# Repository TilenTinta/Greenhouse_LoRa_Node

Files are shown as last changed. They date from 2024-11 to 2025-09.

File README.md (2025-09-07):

# Greenhouse LoRa Node

**Greenhouse LoRa Node** is an open-source monitoring system designed for use in greenhouses, orchards or other agricultural environments. This project includes all the necessary components to build the system, including:

- A custom PCB for the node (supports LoRa or SIM card communication),
- Firmware for the PCB,
- PCB casing,
- Server terminal application,
- GUI template using Grafana.

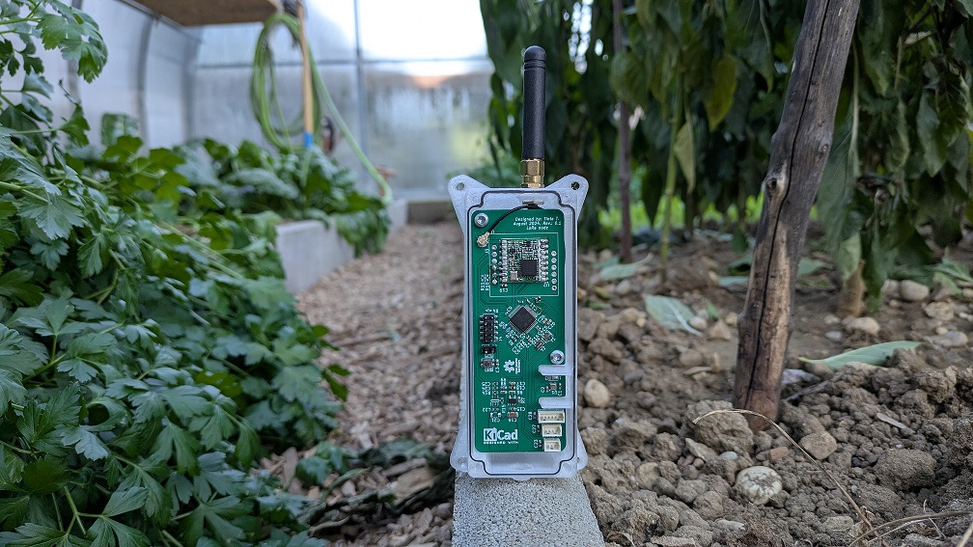
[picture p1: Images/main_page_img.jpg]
Greenhouse LoRa Node


---

## PCB

The PCB is a two-layer board that integrates essential hardware components. It is versatile and supports different communication modules. Users can choose between a LoRa module or a SIM card module (both cannot be used simultaneously). 

### Features
- LDO voltage regulator - 3.3V for mcu and sensors.
- Direct battery power if STM32L151 is used,
- Step-up converter - 4V for SIM module only,
- Battery voltage monitoring,
- Battery cell holder for 18650 cells,
- Three connectors:
  - Earth humidity probe
  - AUX1 (I2C interface)
  - AUX2 (SPI interface),
- Support for LoRa module (RFM95W / SX1276) or SIM module (SIM800L),
- u.FL antenna connector,
- BME280 sensor (measures air temperature, humidity, and pressure),
- MCU: STM32F103C8T6 or STM32L151C8T6,
- 10-pin JTAG programming connector.

---

## Firmware

The firmware is written entirely in C using STM CubeIDE. It is designed to be easily updated or modified. The MCU supports multiple sleep modes for power optimization, which can be configured directly in the code.

The project does not include the `keys.h` file, as it contains user-specific information. The structure of the `keys.h` file is as follows:

```c
#ifndef KEYS_H_
#define KEYS_H_

#define DEVICE_ID            1       // ID number of the node

#define DEVICE_ADDRESS       {0x01, 0x23, 0x45, 0x56}
#define APPSKEY              {0x01, 0x23, 0x45, 0x67, 0x89, 0x10, 0x11, 0x12, 0x13, 0x14, 0x15, 0x16, 0x17, 0x18, 0x19, 0x20}
#define NWKSKEY              {0x01, 0x23, 0x45, 0x67, 0x89, 0x10, 0x11, 0x12, 0x13, 0x14, 0x15, 0x16, 0x17, 0x18, 0x19, 0x20}

#endif
```

The library for the RFM95W LoRa module is based on the repository linked below, with slight modifications made for this project: [https://github.com/henriheimann/stm32-hal-rfm95](https://github.com/henriheimann/stm32-hal-rfm95)

> [!CAUTION]
> When using the **RFM95W LoRa module** and the graphical peripheral editor in **CubeIDE**, additional code modifications are required. After saving changes in the IDE, the auto-generated code will be overwritten, re-enabling all IRQs by default. 
> The **RFM95W module** generates a 1 MHz digital signal on one of its IRQ pins at boot. If interrupts are not properly initialized, this can trigger errors in the MCU. To prevent this issue, **all interrupts must be disabled until the module is fully initialized**.

This project includes two firmware versions for two different microcontrollers. The firmware in the `Firmware_F103` folder was written for the STM32F103xx microcontroller and represents the initial version of the firmware. Due to issues with power consumption, the microcontroller was replaced with an STM32L151xx. The firmware in the `Firmware_L151` folder is the latest version, incorporating all modifications made to the PCB.

### Current consumption:
The current firmware is optimized for the LoRa module and uses Standby sleep mode. In this configuration, the PCB draws ~60 µA while asleep. This isn’t ideal yet, but it’s sufficient for initial tests. Bench measurements suggest the remaining overhead lies between the MCU and the RFM95W.
At 60 µA, a 3500 mAh 18650 cell yields a theoretical battery life of ~6 years, not accounting for self-discharge, temperature...

---

## Case

The PCB case is 3D printed using PETG filament on a standard FDM 3D printer. When deploying the node outdoors, ensure the filament can withstand UV exposure. Materials like ASA or ABS might be more suitable for such environments.

### Design Features:
- The case has a dedicated section with perforations to allow airflow near the sensor, enabling accurate air parameter measurements while protecting the rest of the PCB from external conditions.
- A groove runs along the perimeter of the lower part of the case, designed to fit a 3D-printed seal made from flexible materials like TPU or TPE. This ensures a better seal to protect the internal components.

### Notes:
- The design is optimized for easy replication using commonly available 3D printing materials and techniques.
- Consider using higher-temperature and UV-resistant materials for long-term outdoor use.

---

## Server Application

The server application is entirely written in Python and is terminal-based. Every operation performed by the application is logged into a log file for future inspection in case of issues. 

### Features
- Connects to your LoRaWAN devices on TTN via MQTT.
- Configurable `ttn_config.json` for easy integration.
- Configurable `InfluxDB_config.json` for easy integration.
- Supports multiple devices under a single application.

### Configuration Files

Upon boot, the application requires two JSON files to load all the configurations for the database and MQTT connection to the TTN broker:

1. **`InfluxDB_config.json`**  
   Configuration file for connecting to the InfluxDB database:
   ```json
   {
       "_comment": "JSON config file for database connection",
       "url": "http://localhost:8086",
       "org": "tinta",
       "token": "XXXXXXXXXXXXXXXXXXXXXXXXXXXXXXXXXXXXXXXXXX",
       "bucket": "bucket_name",
       "timezone": "Europe/Ljubljana"
   }
    ```

2. **`ttn_config.json`** 
    ```json
    {
        "_comment": "JSON config file for mqttTTN connection",
        "app_id": "lora-home-node",
        "username": "lora-home-node@ttn",
        "access_key": "XXXXXXXXXXXXXXXXXXXXXXXXXXX.XXXXXXXXXXXXXXXXXXXXXXXXX",
        "mqtt_broker": "eu1.cloud.thethings.network",
        "mqtt_port": 1883,
        "topic": "v3/lora-home-node@ttn/devices/+/up" 
    }
    ```

### Prerequirements

Before running the application, ensure you have the required dependencies installed. The following packages are necessary:

``` bash
pip install json paho-mqtt psycopg2 influxdb-client pytz logging socket base64
```

---

## Database

This project utilizes **InfluxDB** as its primary database solution. InfluxDB was selected due to its high efficiency in handling time-series data and its seamless integration with **Grafana**, which simplifies data visualization and analysis. By leveraging InfluxDB's ability to store data in a **time-series format**, this project ensures scalability for managing and analyzing temporal data.

### Notes:
- Ensure that InfluxDB is properly configured to handle the expected volume of data from the monitoring nodes.

---

## Grafana

This repository contains pre-configured Grafana UI files designed to read and present data from sensors in an intuitive and visually appealing way. These files provide a basic setup to help you quickly get started with monitoring and analyzing your sensor data using Grafana's powerful dashboard capabilities.

### Requirements:
- **Grafana** and **InfluxDB** should be installed on either a Raspberry Pi or a home server (depending on your setup).
- Ensure the terminal application is run on the same machine where the database and Grafana are installed.

---

## Docker Setup

This repository includes Docker support for easier and faster deployment on the server-side. The Docker setup contains:
- **InfluxDB** (Database)
- **Grafana** (Visualization Tool)
- **Python Server Application** (`server_app`)

> [!CAUTION]
Before running the Docker setup, the `docker-compose.yml` file must be modified to suit your specific preferences, such as:
- Network configurations,
- Volume mappings,
- Environment variables for InfluxDB, Grafana, and the Python application,
- Ports for external access,
- etc.

### Building the Container

To build the Docker containers, first navigate to the `Docker` folder in your terminal:

``` bash
cd /path/to/Docker
```
then run:
``` bash
docker-compose build
```
Once the container is build start it and set it up as you want.
``` bash
docker-compose up -d
```

### Acces containers
After running the containers, you can access:
- Grafana: http://localhost:3000 (default credentials: admin / admin123)
- InfluxDB: http://localhost:8086 (default credentials: admin / admin123)

Make sure your Grafana instance is properly configured to read from InfluxDB.

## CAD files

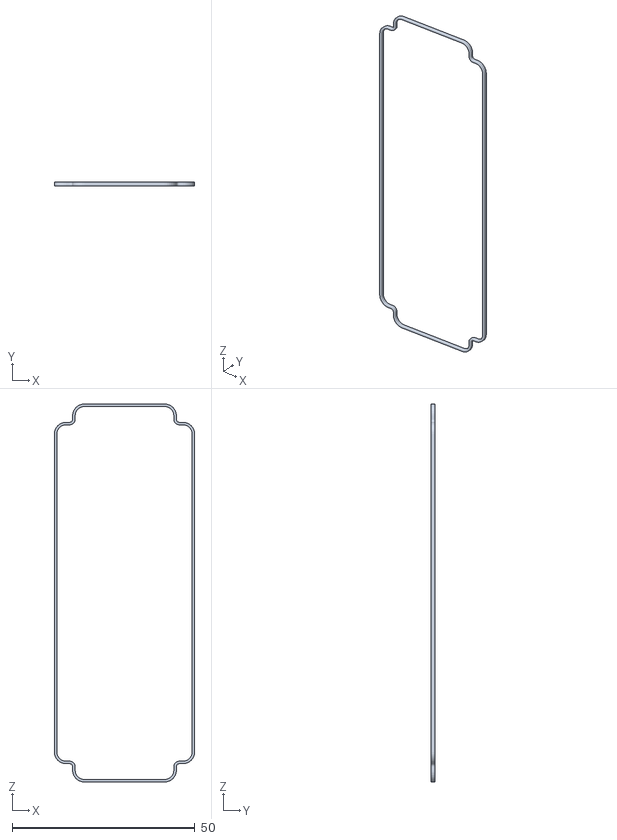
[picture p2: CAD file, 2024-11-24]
STL/Sealing v3.stl
38.4 x 1.10 x 103.4

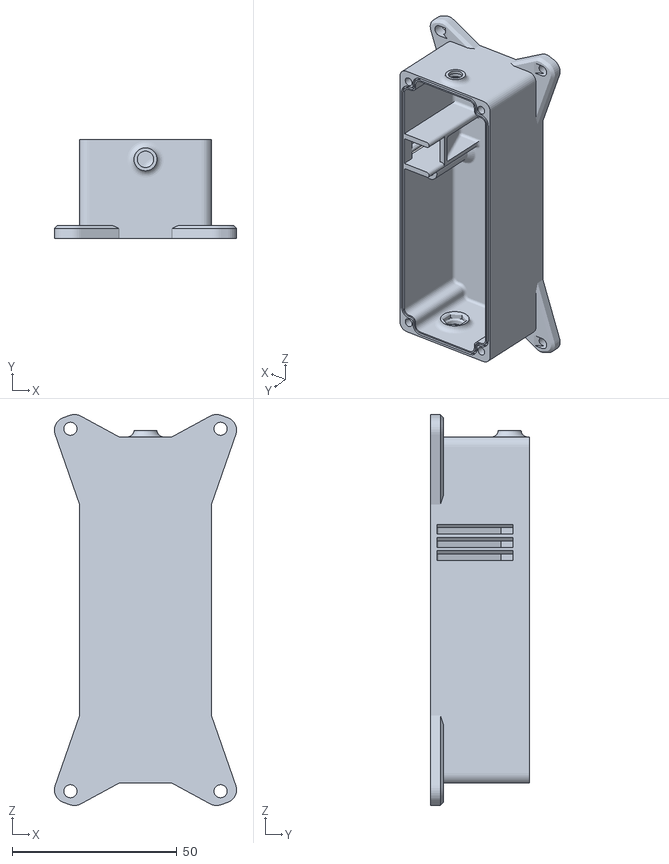
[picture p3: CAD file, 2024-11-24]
STL/PCB_case v31.stl
55.3 x 30.0 x 118.6

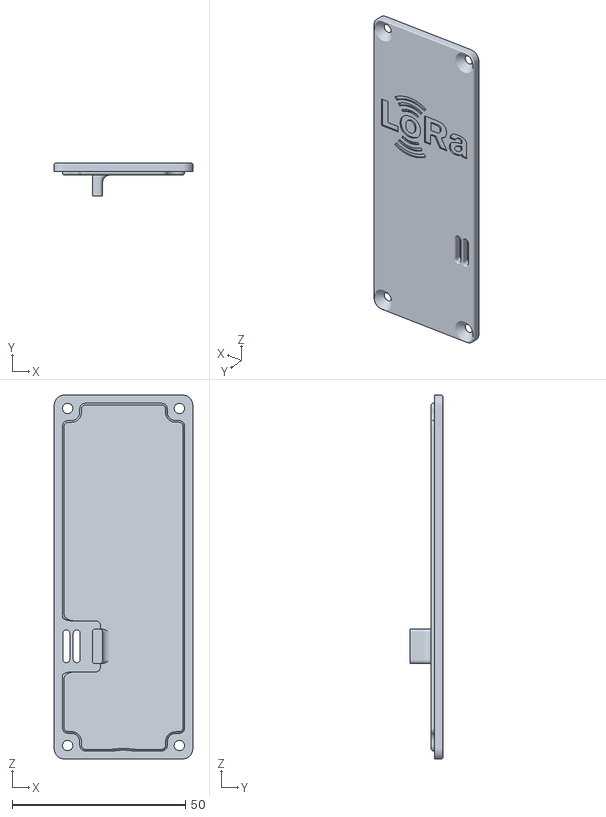
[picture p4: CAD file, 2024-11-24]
STL/PCB_lid v17.stl
40.0 x 9.50 x 105.0

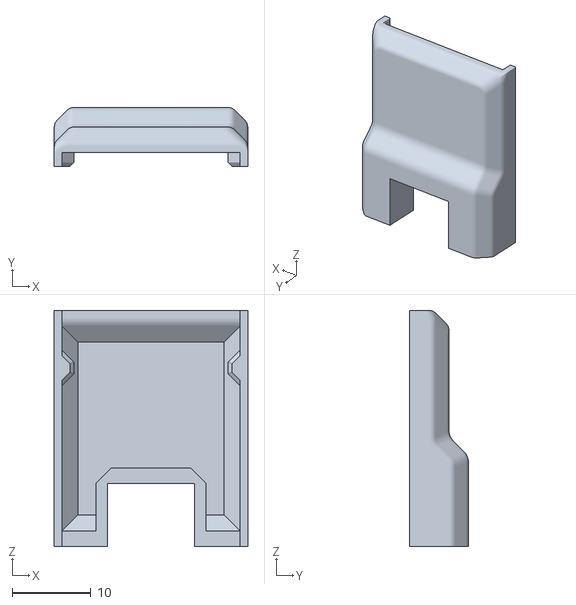
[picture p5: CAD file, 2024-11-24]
STL/Ground_sensor_cover v9.stl
24.6 x 7.50 x 30.0

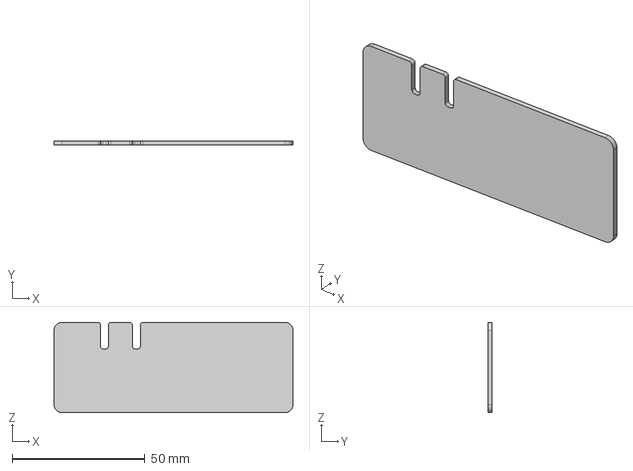
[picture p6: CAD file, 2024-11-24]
STL/PCB_base v15.step
90.0 x 1.60 x 34.0 mm

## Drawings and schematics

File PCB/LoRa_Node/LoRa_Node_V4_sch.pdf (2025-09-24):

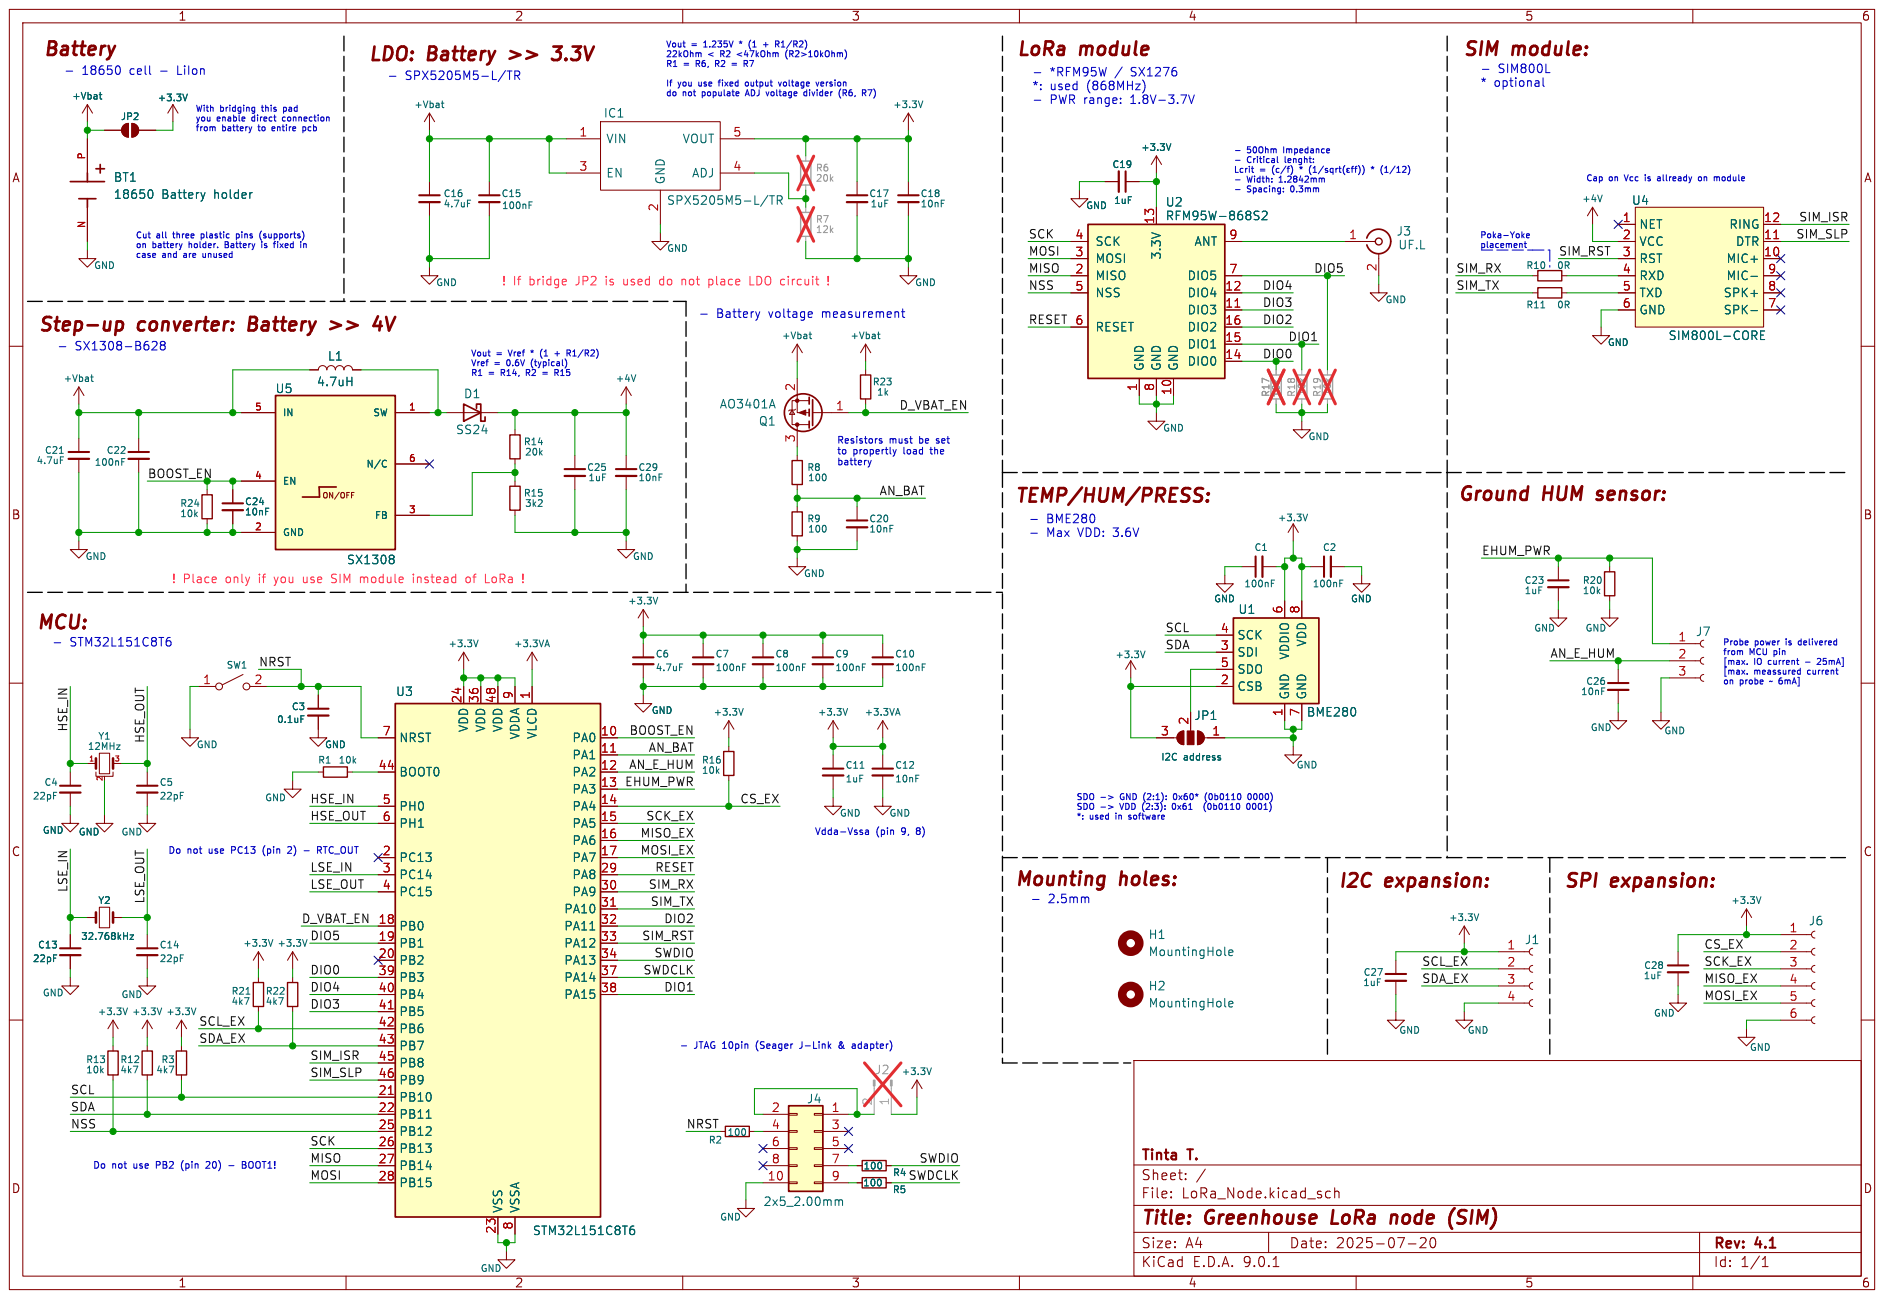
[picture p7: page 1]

RESET NSS LoRa module
+3.3V GND

you enable direct connection

case and are unused

- Max VDD: 3.6V Mounting holes:

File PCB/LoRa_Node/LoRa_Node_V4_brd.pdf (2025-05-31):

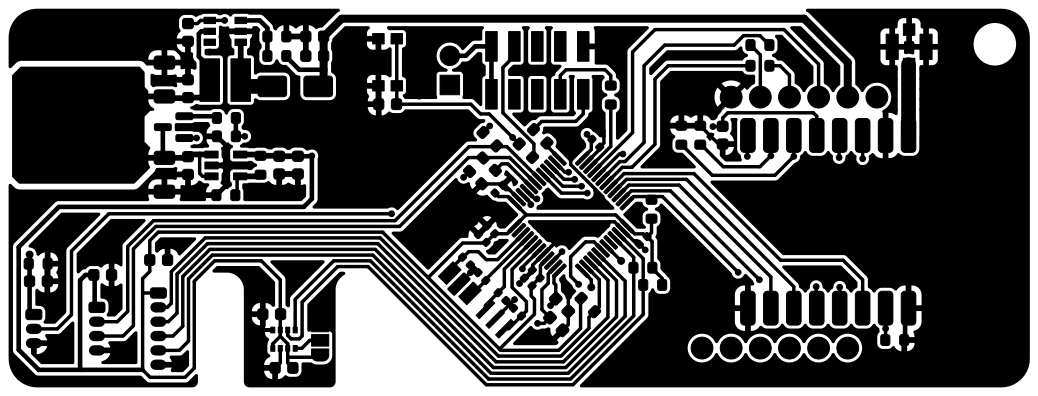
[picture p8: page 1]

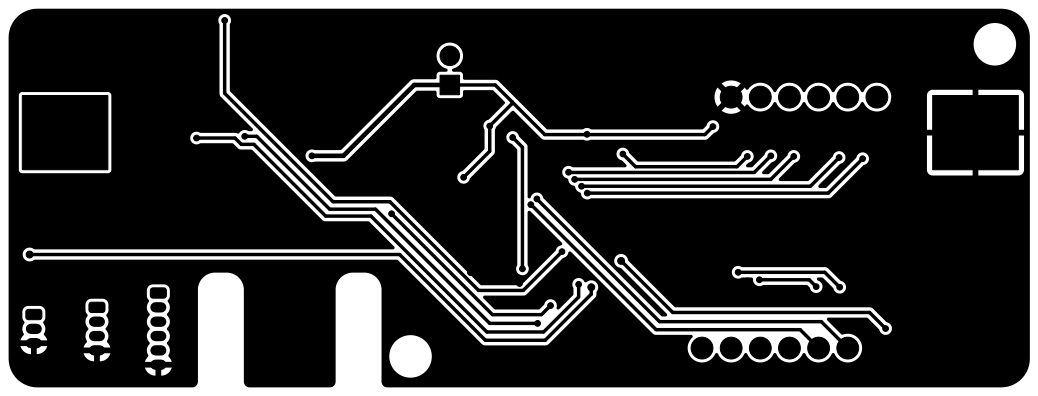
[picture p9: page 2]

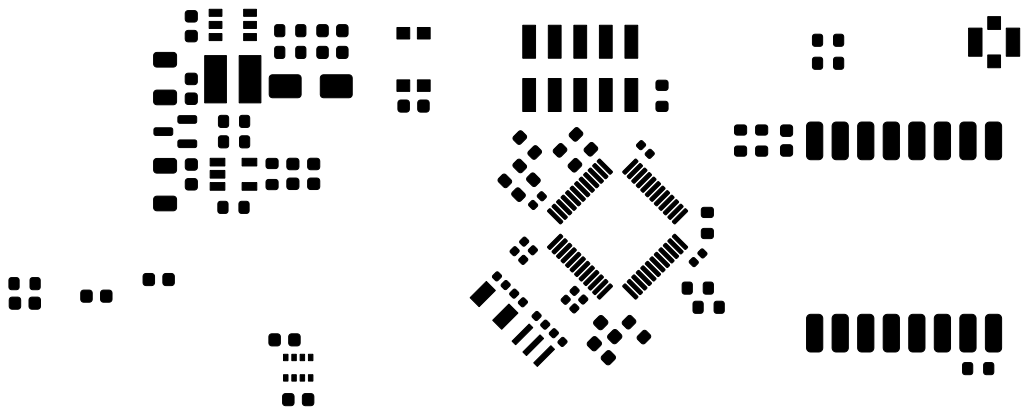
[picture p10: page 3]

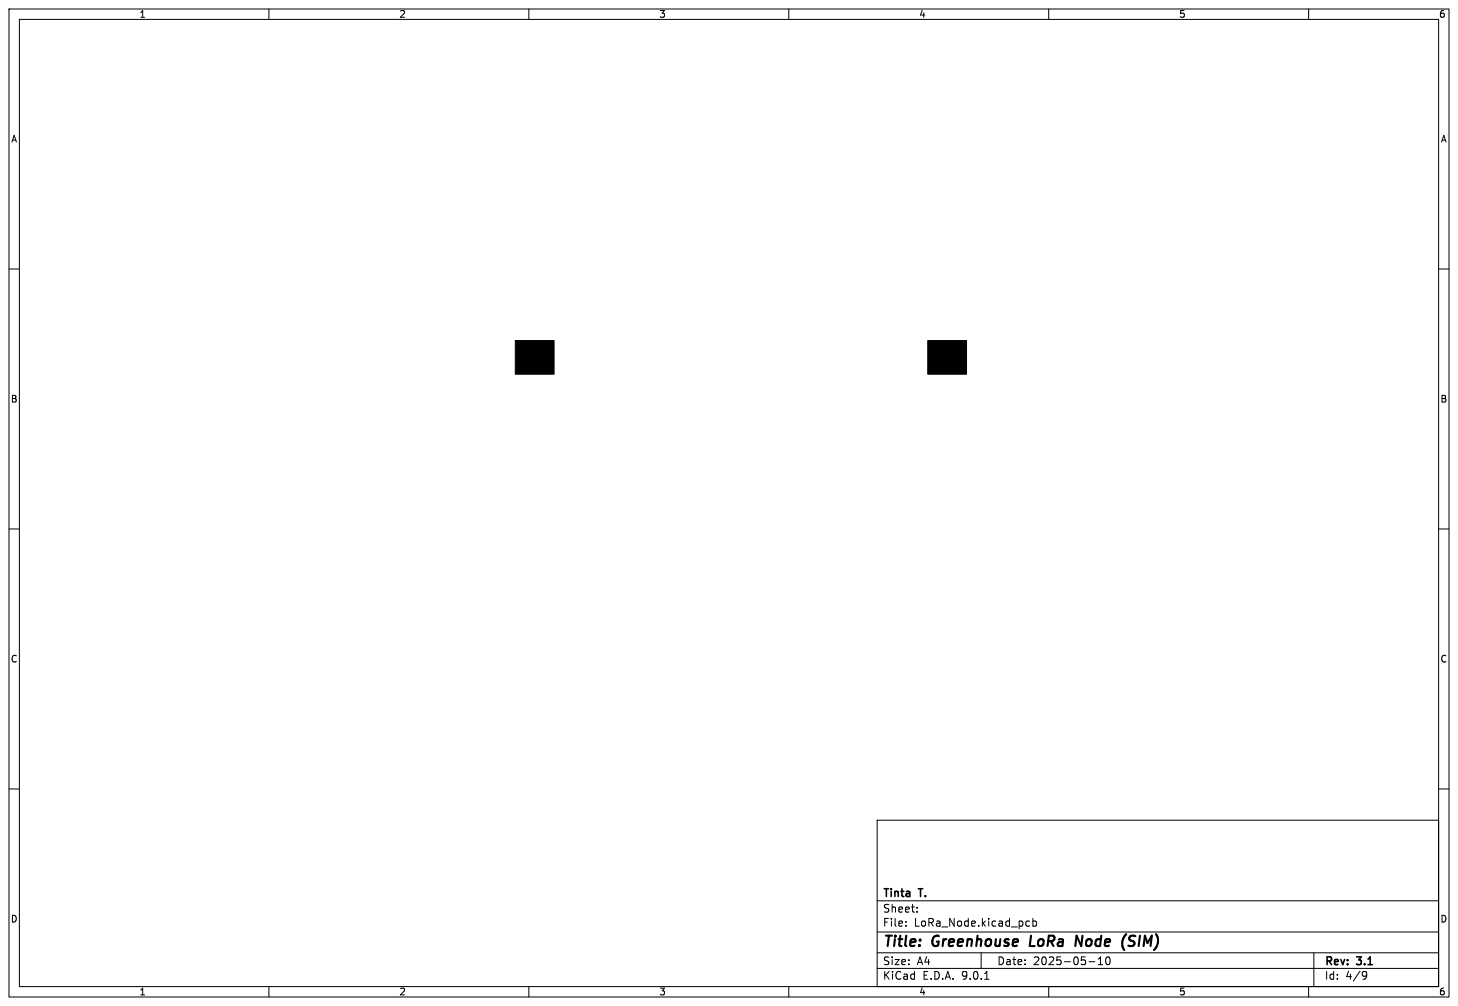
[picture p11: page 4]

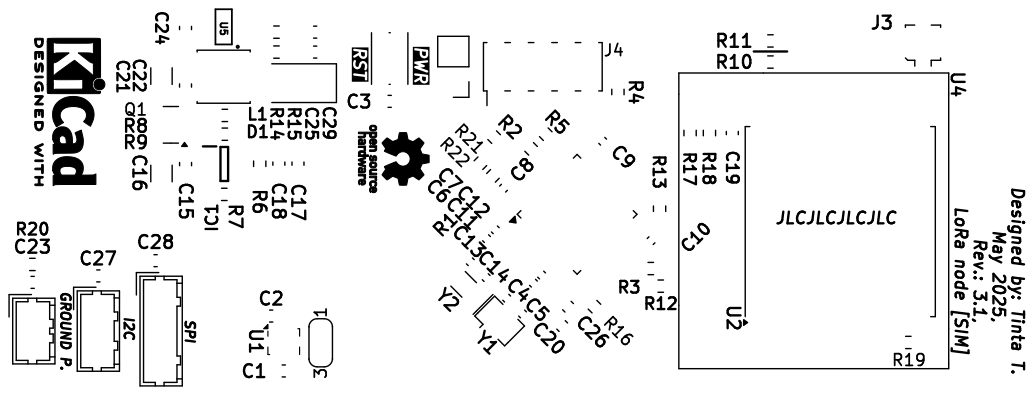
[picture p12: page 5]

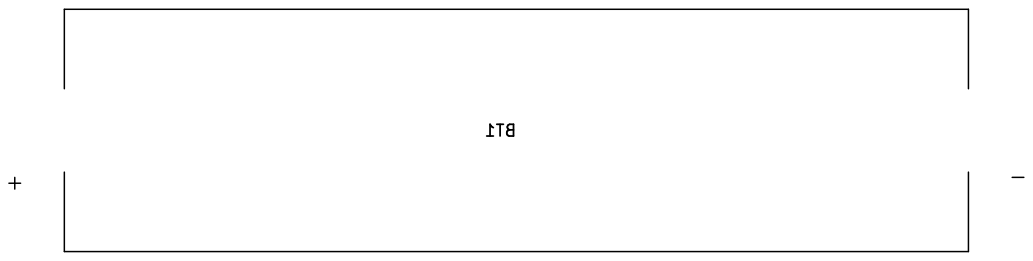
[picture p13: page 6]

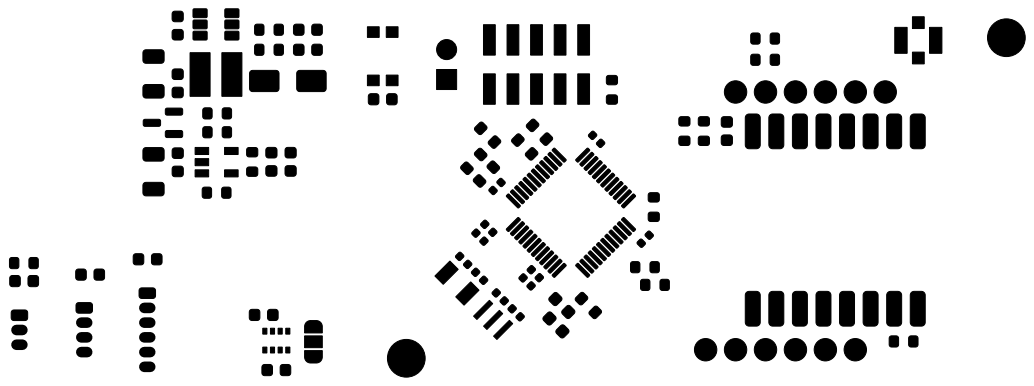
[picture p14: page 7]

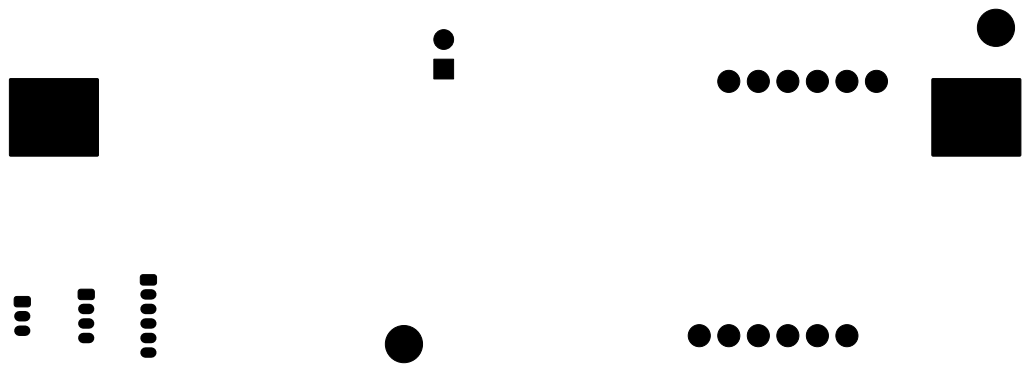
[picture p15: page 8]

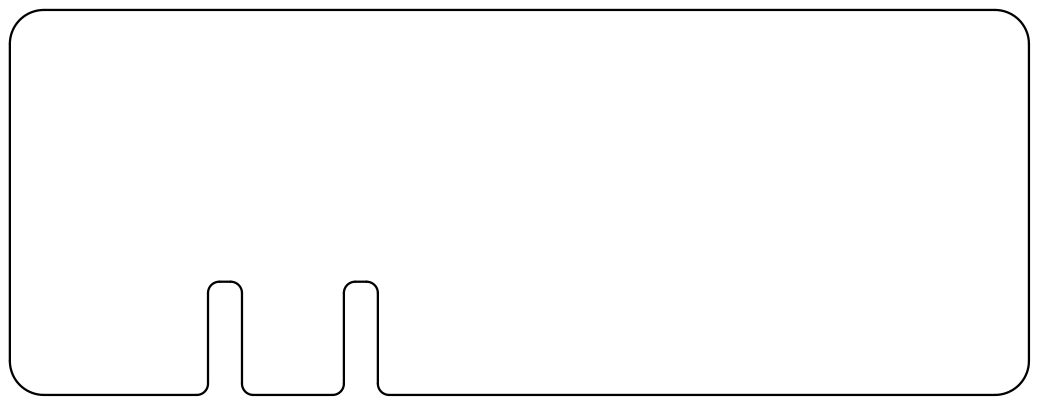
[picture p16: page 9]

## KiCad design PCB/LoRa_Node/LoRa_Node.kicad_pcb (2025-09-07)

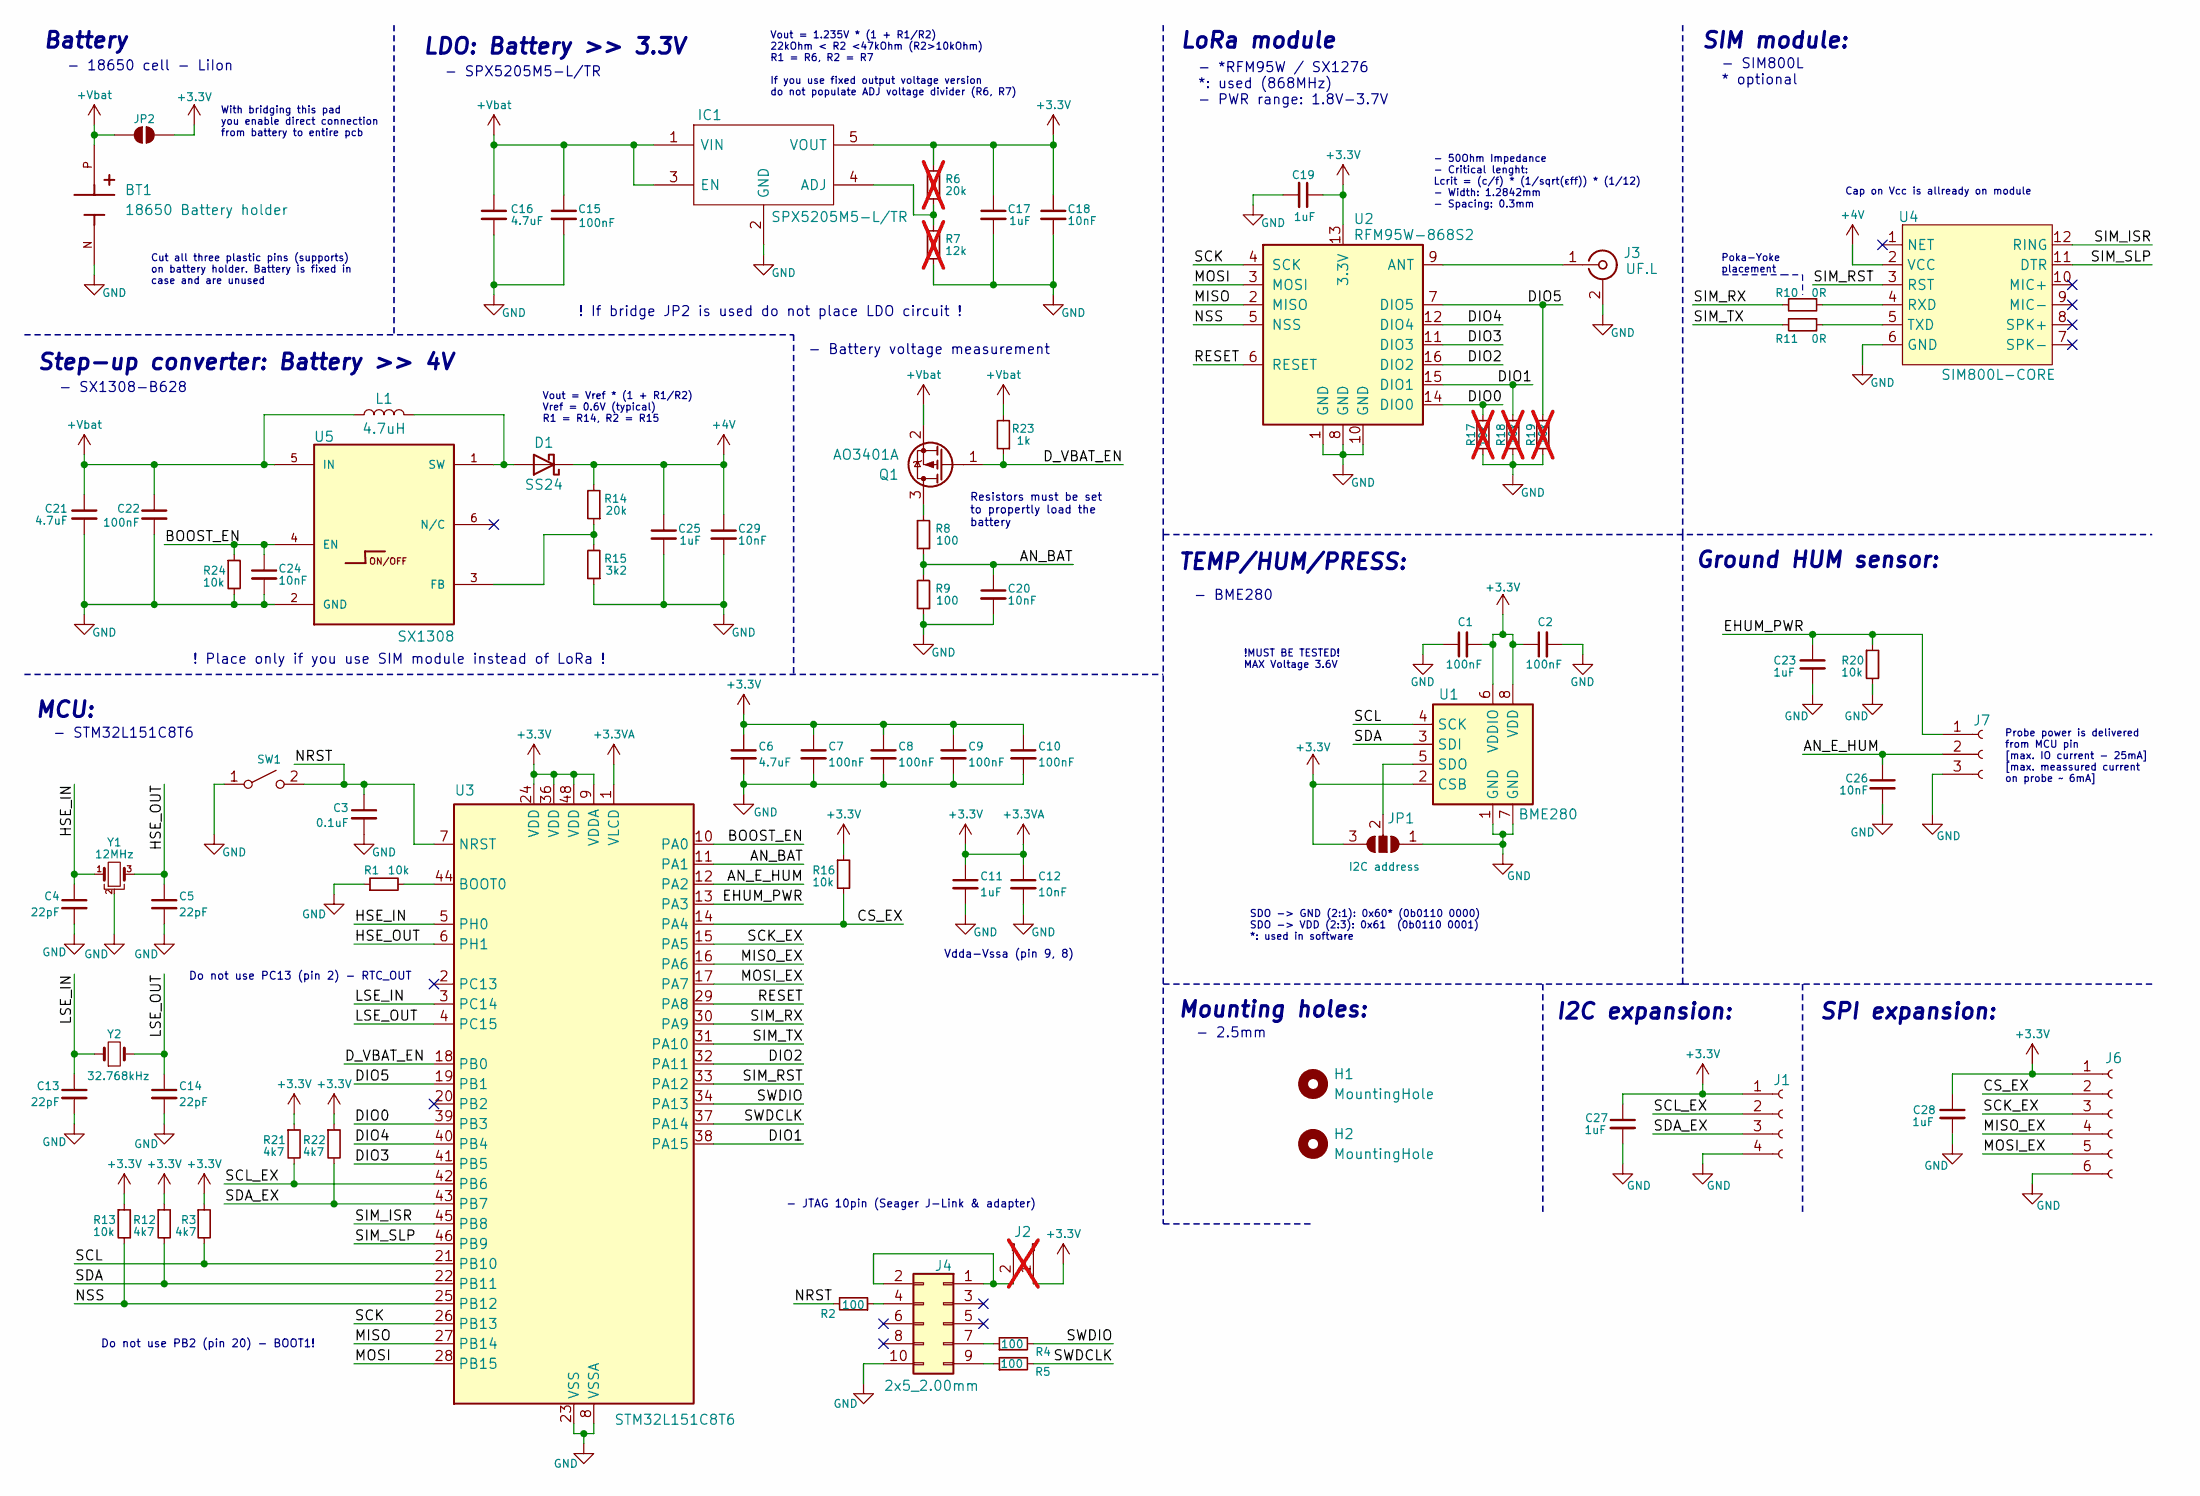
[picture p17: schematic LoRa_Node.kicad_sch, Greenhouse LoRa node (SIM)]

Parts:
BT1: 18650 Battery holder; PARTREV E
C1, C2, C15, C22: 100nF; C_0603_1608Metric
C3: 0.1uF; C_0603_1608Metric
C4, C5, C13, C14: 22pF; C_0402_1005Metric
C6: 4.7uF; C_0402_1005Metric
C7, C8, C9, C10: 100nF; C_0402_1005Metric
C11: 1uF; C_0402_1005Metric
C12: 10nF; C_0402_1005Metric
C16, C21: 4.7uF; C_1206_3216Metric
C17, C19, C23, C25, C27, C28: 1uF; C_0603_1608Metric
C18, C20, C24, C26, C29: 10nF; C_0603_1608Metric
D1: SS24; D_SMA
H1, H2: MountingHole; MountingHole_3.2mm_M3
IC1: SPX5205M5-L/TR; SOT95P280X145-5N; Manufacturer_Part_Number SPX5205M5-L-3-3/TR; Mouser Part Number 701-SPX5205M5-L-33TR
J1: Conn_01x04_Socket; Hirose_DF13-04P-1.25DSA_1x04_P1.25mm_Vertical
J2: Conn_01x02_Pin; PinHeader_1x02_P2.54mm_Vertical; not fitted
J3: UF.L; U.FL_Molex_MCRF_73412-0110_Vertical
J4: 2x5_2.00mm; PinHeader_2x05_P2.00mm_Vertical_SMD
J6: Conn_01x06_Socket; Hirose_DF13-06P-1.25DSA_1x06_P1.25mm_Vertical
J7: Conn_01x03_Socket; Hirose_DF13-03P-1.25DSA_1x03_P1.25mm_Vertical
JP1: I2C address; SolderJumper-3_P1.3mm_Open_RoundedPad1.0x1.5mm_NumberLabels
JP2: SolderJumper_2_Open; SolderJumper-2_P1.3mm_Open_RoundedPad1.0x1.5mm
L1: 4.7uH; L_Cenker_CKCS4020
Q1: AO3401A; SOT-23
R1, R13, R16, R20, R24: 10k; R_0603_1608Metric
R2, R4, R5, R8, R9: 100; R_0603_1608Metric
R3, R12, R21, R22: 4k7; R_0603_1608Metric
R6: 20k; R_0603_1608Metric; not fitted
R7: 12k; R_0603_1608Metric; not fitted
R10, R11: 0R; R_0603_1608Metric
R14: 20k; R_0603_1608Metric
R15: 3k2; R_0603_1608Metric
R17, R18, R19: 10k; R_0603_1608Metric; not fitted
R23: 1k; R_0603_1608Metric
SW1: SW_SPST; SW_Push_1P1T_NO_CK_KMR2
U1: BME280; Bosch_LGA-8_2x2.5mm_P0.65mm_ClockwisePinNumbering
U2: RFM95W-868S2; HOPERF_RFM9XW_SMD
U3: STM32L151C8T6; LQFP-48_7x7mm_P0.5mm
U4: SIM800L-CORE
U5: SX1308; SOT-23-6
Y1: 12MHz; Resonator_SMD_Murata_CSTxExxV-3Pin_3.0x1.1mm
Y2: 32.768kHz; Crystal_SMD_3215-2Pin_3.2x1.5mm

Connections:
+3.3V: C1.2, C2.1, C6.1, C7.1, C8.1, C9.1, C10.1, C11.1, C12.1, C17.1, C18.1, C19.1, C27.1, C28.1, IC1.5 (VOUT), J1.1, J2.1, J6.1, JP1.3 (B), JP2.2 (B), R3.1, R6.2, R12.1, R13.1, R16.1, R21.1, R22.1, U1.2 (CSB), U1.6 (VDDIO), U1.8 (VDD), U2.13 (3.3V), U3.1 (VLCD), U3.9 (VDDA), U3.24 (VDD), U3.36 (VDD), U3.48 (VDD)
+4V: C25.1, C29.1, D1.1 (K), R14.2, U4.2 (VCC)
+Vbat: BT1.P, C15.1, C16.1, C21.1, C22.1, IC1.1 (VIN), IC1.3 (EN), JP2.1 (A), L1.1, Q1.2 (S), R23.2, U5.5 (IN)
/AN_BAT: C20.1, R8.1, R9.2, U3.11 (PA1)
/AN_E_HUM: C26.1, J7.2, U3.12 (PA2)
/BOOST_EN: C24.1, R24.1, U3.10 (PA0), U5.4 (EN)
/CS_EX: J6.2, R16.2, U3.14 (PA4)
/DIO0: R17.2, U2.14 (DIO0), U3.39 (PB3)
/DIO1: R18.2, U2.15 (DIO1), U3.38 (PA15)
/DIO2: U2.16 (DIO2), U3.32 (PA11)
/DIO3: U2.11 (DIO3), U3.41 (PB5)
/DIO4: U2.12 (DIO4), U3.40 (PB4)
/DIO5: R19.2, U2.7 (DIO5), U3.19 (PB1)
/D_VBAT_EN: Q1.1 (G), R23.1, U3.18 (PB0)
/EHUM_PWR: C23.1, J7.1, R20.1, U3.13 (PA3)
/HSE_IN: C4.1, U3.5 (PH0), Y1.1
/HSE_OUT: C5.1, U3.6 (PH1), Y1.3
/LSE_IN: C13.1, U3.3 (PC14), Y2.1
/LSE_OUT: C14.1, U3.4 (PC15), Y2.2
/MISO: U2.2 (MISO), U3.27 (PB14)
/MISO_EX: J6.4, U3.16 (PA6)
/MOSI: U2.3 (MOSI), U3.28 (PB15)
/MOSI_EX: J6.5, U3.17 (PA7)
/NRST: C3.1, R2.2, SW1.2 (B), U3.7 (NRST)
/NSS: R13.2, U2.5 (NSS), U3.25 (PB12)
/RESET: U2.6 (RESET), U3.29 (PA8)
/SCK: U2.4 (SCK), U3.26 (PB13)
/SCK_EX: J6.3, U3.15 (PA5)
/SCL: R3.2, U1.4 (SCK), U3.21 (PB10)
/SCL_EX: J1.2, R21.2, U3.42 (PB6)
/SDA: R12.2, U1.3 (SDI), U3.22 (PB11)
/SDA_EX: J1.3, R22.2, U3.43 (PB7)
/SIM_ISR: U3.45 (PB8), U4.12 (RING)
/SIM_RST: U3.33 (PA12), U4.3 (RST)
/SIM_RX: R10.2, U3.30 (PA9)
/SIM_SLP: U3.46 (PB9), U4.11 (DTR)
/SIM_TX: R11.2, U3.31 (PA10)
/SWDCLK: R5.2, U3.37 (PA14)
/SWDIO: R4.2, U3.34 (PA13)
GND: BT1.N, C1.1, C2.2, C3.2, C4.2, C5.2, C6.2, C7.2, C8.2, C9.2, C10.2, C11.2, C12.2, C13.2, C14.2, C15.2, C16.2, C17.2, C18.2, C19.2, C20.2, C21.2, C22.2, C23.2, C24.2, C25.2, C26.2, C27.2, C28.2, C29.2, IC1.2 (GND), J1.4, J3.2 (Ext), J4.10, J6.6, J7.3, JP1.1 (A), R1.1, R7.1, R9.1, R15.1, R17.1, R18.1, R19.1, R20.2, R24.2, SW1.1 (A), U1.1 (GND), U1.7 (GND), U2.1 (GND), U2.8 (GND), U2.10 (GND), U3.8 (VSSA), U3.23 (VSS), U3.35 (VSS), U3.47 (VSS), U4.6 (GND), U5.2 (GND), Y1.2
unnamed: D1.2 (A), L1.2, U5.1 (SW)
unnamed: IC1.4 (ADJ), R6.1, R7.2
unnamed: J2.2, J4.1, J4.2
unnamed: J3.1 (In), U2.9 (ANT)
unnamed: J4.4, R2.1
unnamed: J4.7, R4.1
unnamed: J4.9, R5.1
unnamed: JP1.2 (C), U1.5 (SDO)
unnamed: Q1.3 (D), R8.2
unnamed: R1.2, U3.44 (BOOT0)
unnamed: R10.1, U4.4 (RXD)
unnamed: R11.1, U4.5 (TXD)
unnamed: R14.1, R15.2, U5.3 (FB)

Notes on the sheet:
LDO: Battery >> 3.3V
- SX1308-B628
Probe power is delivered from MCU pin [max. IO current - 25mA] [max. meassured current on probe ~ 6mA]
- BME280
LoRa module
!MUST BE TESTED! MAX Voltage 3.6V
With bridging this pad you enable direct connection from battery to entire pcb
Mounting holes:
Cut all three plastic pins (supports) on battery holder. Battery is fixed in case and are unused
- Battery voltage measurement
Vout = 1.235V * (1 + R1/R2) 22kOhm < R2 <47kOhm (R2>10kOhm) R1 = R6, R2 = R7 If you use fixed output voltage version do not populate ADJ voltage divider (R6, R7)
SPI expansion:
- SIM800L * optional
Do not use PC13 (pin 2) - RTC_OUT
SDO -> GND (2:1): 0x60* (0b0110 0000) SDO -> VDD (2:3): 0x61 (0b0110 0001) *: used in software
- SPX5205M5-L/TR
Vdda-Vssa (pin 9, 8)
Ground HUM sensor:
- 2.5mm
Battery
! If bridge JP2 is used do not place LDO circuit !
Poka-Yoke placement
MCU:
! Place only if you use SIM module instead of LoRa !
Cap on Vcc is allready on module
- 50Ohm Impedance - Critical lenght: Lcrit = (c/f) * (1/sqrt(εff)) * (1/12) - Width: 1.2842mm - Spacing: 0.3mm
Resistors must be set to propertly load the battery
Vout = Vref * (1 + R1/R2) Vref = 0.6V (typical) R1 = R14, R2 = R15
- 18650 cell - LiIon
Step-up converter: Battery >> 4V
TEMP/HUM/PRESS:
Do not use PB2 (pin 20) - BOOT1!
- STM32L151C8T6
I2C expansion:
- *RFM95W / SX1276 *: used (868MHz) - PWR range: 1.8V-3.7V
- JTAG 10pin (Seager J-Link & adapter)
SIM module:

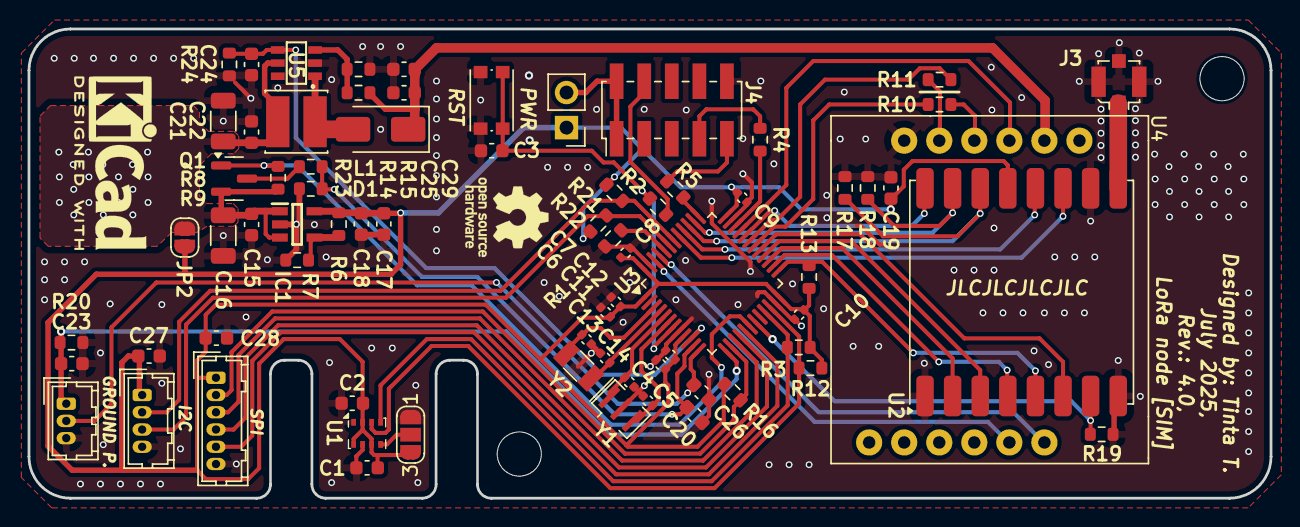
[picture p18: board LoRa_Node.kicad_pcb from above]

Board: 2 copper layers, 90.0 x 34.0 mm, 76 parts (1 on the bottom side), 53 nets.

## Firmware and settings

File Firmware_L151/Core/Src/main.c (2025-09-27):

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
/* Includes ------------------------------------------------------------------*/
#include "main.h"

/* USER CODE BEGIN Includes */

#ifdef USE_EEPROM
	#include "eeprom.h"
#else
	#include "flash.h"
#endif

/* USER CODE END Includes */

/* USER CODE BEGIN PD */

BME280 				bme280;
MEASUREMENTS 		measurements;
LORA_Data 			lora_data;
rfm95_handle_t 		rfm95_handle;

RTC_TimeTypeDef 	time;
RTC_DateTypeDef 	date;
RTC_AlarmTypeDef 	sAlarm;

/* USER CODE END PD */

ADC_HandleTypeDef hadc;

I2C_HandleTypeDef hi2c1;
I2C_HandleTypeDef hi2c2;

RTC_HandleTypeDef hrtc;

SPI_HandleTypeDef hspi1;
SPI_HandleTypeDef hspi2;

TIM_HandleTypeDef htim2;
TIM_HandleTypeDef htim3;

void SystemClock_Config(void);
static void MX_GPIO_Init(void);
static void MX_RTC_Init(void);
static void MX_SPI2_Init(void);
static void MX_I2C1_Init(void);
static void MX_I2C2_Init(void);
static void MX_SPI1_Init(void);
static void MX_ADC_Init(void);
static void MX_TIM2_Init(void);
static void MX_TIM3_Init(void);
/* USER CODE BEGIN 0 */

/* VARIABLES */
uint8_t awake = 1;				// Detect wake up event
uint8_t state = STATE_INIT;		// state value for state machine
volatile uint32_t tim3_tick_msb = 0;
volatile uint8_t adc_substate = 0; // 0 = battery next, 1 = soil humidity next


/* MY FUNCTIONS */
void RFM95W_Struct_Init(rfm95_handle_t* rfm95_handle);
static uint8_t random_int(uint8_t max);
static uint32_t get_precision_tick();
void wake_up_from_standby_handler(void);
void HAL_RTC_AlarmAEventCallback(RTC_HandleTypeDef *hrtc);
static void ADC_SelectChannel(uint32_t channel);

/* USER CODE END 0 */

/**
  * @brief  The application entry point.
  * @retval int
  */
int main(void)
{

  /* MCU Configuration--------------------------------------------------------*/

  /* Reset of all peripherals, Initializes the Flash interface and the Systick. */
  HAL_Init();

  /* Configure the system clock */
  SystemClock_Config();

  /* Initialize all configured peripherals */
  MX_GPIO_Init();
  MX_RTC_Init();
  MX_SPI2_Init();
  MX_I2C1_Init();
  MX_I2C2_Init();
  MX_SPI1_Init();
  MX_ADC_Init();
  MX_TIM2_Init();
  MX_TIM3_Init();
  /* USER CODE BEGIN 2 */

  float delta = 100.0f / (EARTH_HUM_DRY_VAL -  EARTH_HUM_WET_VAL); // Precalculated value
  uint8_t status = 0;
  uint32_t tx_count = 0; // Read number of TX packets from flash

  // Check if the MCU woke up from Standby mode - not mainly used -> not completely tested //
//  	#ifndef SLEEP_MODE_STOP
//  	  if (__HAL_PWR_GET_FLAG(PWR_FLAG_SB)) // Standby flag is set
//  		  {
//  			  // Clear the Standby flag
//  			  __HAL_PWR_CLEAR_FLAG(PWR_FLAG_SB);
//
//  			  // Check if RTC Alarm A triggered the wake-up
//  			  if (__HAL_RTC_ALARM_GET_FLAG(&hrtc, RTC_FLAG_ALRAF) != RESET)
//  			  {
//  				  // Clear the RTC Alarm A flag
//  				  __HAL_RTC_ALARM_CLEAR_FLAG(&hrtc, RTC_FLAG_ALRAF);
//
//  				  // Perform wake-up logic
//  				  wake_up_from_standby_handler();
//  			  }
//  		  }
//  	#endif

  /* USER CODE END 2 */

  /* Infinite loop */
  /* USER CODE BEGIN WHILE */
  while (1)
  {
	  /* MAIN STATE MACHINE */
	  switch(state)
	  {


	  ////////* DEVICE BOOT *////////
	  case STATE_INIT:

		  if (measurements.ADC_read_cnt == 0 && measurements.init_end == 0)
		  {
			  /* BME280 */
			  status += BME280_Reset(&bme280, &hi2c2);
			  HAL_Delay(200);
			  status += BME280_ReadDeviceID(&bme280, &hi2c2);
			  status += BME280_ReadCalibData(&bme280, &hi2c2);
			  status += BME280_Init(&bme280, &hi2c2);

			  // Enable power to humidity probe and to voltage divider for battery measurement
			  HAL_GPIO_WritePin(EHUM_PWR_GPIO_Port, EHUM_PWR_Pin, GPIO_PIN_SET);
			  HAL_GPIO_WritePin(D_VBAT_EN_GPIO_Port, D_VBAT_EN_Pin, GPIO_PIN_RESET);
			  HAL_Delay(100);

			  // Set some pins
			  HAL_GPIO_WritePin(SPI1_CS_EX_GPIO_Port, SPI1_CS_EX_Pin, GPIO_PIN_SET);
			  HAL_GPIO_WritePin(SPI2_NSS_GPIO_Port, SPI2_NSS_Pin, GPIO_PIN_SET);

			  // Disable RTC alarm for init routine
			  __HAL_RTC_ALARM_CLEAR_FLAG(&hrtc, RTC_FLAG_ALRAF);
			  HAL_RTC_DeactivateAlarm(&hrtc, RTC_ALARM_A);

			  HAL_TIM_Base_Start_IT(&htim2);
			  HAL_TIM_Base_Start_IT(&htim3);

			  measurements.init_end = 1;	// Signal init complete
		  }

		  if (measurements.ADC_read_end == 1 && measurements.ADC_read == 1)
		  {
			  // Read analog values
			  measurements.bat_voltage[measurements.ADC_read_cnt] = ADC_Read_Battery(&measurements.ADC_values[0]);
			  measurements.earth_hum[measurements.ADC_read_cnt] = ADC_Read_EHum(&measurements.ADC_values[1], &delta);
			  measurements.ADC_read_cnt ++;

			  measurements.ADC_read_end = 0; 	// reset ADC read flag
			  measurements.ADC_read = 0; 		// reset timer read flag
			  HAL_TIM_Base_Start_IT(&htim2);

			  // Calculate average values
			  if (measurements.ADC_read_cnt == 5)
			  {
				  measurements.ADC_read_cnt = 0;
				  HAL_TIM_Base_Stop_IT(&htim2);

				  // Disable power to humidity probe and to voltage divider for battery measurement
				  HAL_GPIO_WritePin(EHUM_PWR_GPIO_Port, EHUM_PWR_Pin, GPIO_PIN_RESET);
				  HAL_GPIO_WritePin(D_VBAT_EN_GPIO_Port, D_VBAT_EN_Pin, GPIO_PIN_SET);

				  // Calculate average battery voltage
				  measurements.battery_voltage = 0;
				  measurements.earth_humidity = 0;

				  for (int i = 0; i < 5; i++)
				  {
					  measurements.battery_voltage += measurements.bat_voltage[i];
					  measurements.earth_humidity += measurements.earth_hum[i];
				  }

				  measurements.battery_voltage /= 5;
				  measurements.earth_humidity /= 5;

				  // Read all data from BME280 sensor
				  BME280_GoToFromSleep(&bme280, &hi2c2, 1); // wake-up
				  HAL_Delay(100);
				  BME280_ReadAllData(&bme280, &hi2c2);
				  //BME280_GoToFromSleep(&bme280, &hi2c2, 0); // sleep

				  // LoRa module
				  RFM95W_Struct_Init(&rfm95_handle);

				  // Initialise RFM95 module.
				  if (!rfm95_init(&rfm95_handle)) status++;

				  // All that flags must be cleard to get stable boot
				  NVIC_ClearPendingIRQ(EXTI1_IRQn); 		// Clear EXTI1 NVIC pending flag
				  NVIC_ClearPendingIRQ(EXTI3_IRQn); 		// Clear EXTI3 NVIC pending
				  NVIC_ClearPendingIRQ(EXTI15_10_IRQn); 	// Clear EXTI15_10 NVIC pending flag
				  HAL_NVIC_EnableIRQ(EXTI3_IRQn);
				  HAL_NVIC_EnableIRQ(EXTI1_IRQn);
				  //HAL_NVIC_EnableIRQ(EXTI15_10_IRQn); 	// Bricks the program, inturrupt is not needed -> only for RX

				  // Check if everthing is OK (voltage and sensors)
				  if (measurements.battery_voltage < 2.8f) status++; //Vbat NEEDS TO BE SET

				  lora_data.errSendCnt += status;

				  if (status == 0)
				  {
					  //state = STATE_FIRST_CONN;
					  state = STATE_SEND;
					  status = 0;
					  lora_data.errSendCnt = 0;
				  }
				  else
				  {
					  //state = STATE_ERROR;
					  state = STATE_GO_SLEEP;
				  }
			  }
		  }

		  break;



	  ////////* FIRST LoRa/SIM CONNECTION TEST *////////
	  case STATE_FIRST_CONN:

		  // Create data packet that will be send - dummy
		  uint8_t test_data_packet[] = {0x01, 0x02, 0x03, 0x04};

		#ifdef USE_EEPROM
		  EEPROM_Read_Data(FLASH_EEPROM_BASE, &tx_count, 1);
		#else
		  Flash_Read_Data(FLASH_START_ADDR, &tx_count, 1); // 1 = one word
		#endif

		  rfm95_handle.config.tx_frame_count = tx_count;

		  if (!rfm95_send_receive_cycle(&rfm95_handle, test_data_packet, sizeof(test_data_packet)))
		  {
			  // Put device in error state
			  state = STATE_ERROR;
		  }
		  else
		  {
			  // Write number of TX packets to flash
			  uint32_t temp_data = (uint32_t)rfm95_handle.config.tx_frame_count;

			#ifdef USE_EEPROM
			  EEPROM_Write_Data(FLASH_EEPROM_BASE, &temp_data, 1);
			#else
			  Flash_Write_Data(FLASH_START_ADDR, &temp_data, 1); // 1 = one word
			#endif

			  // Put device in sleep
			  state = STATE_GO_SLEEP;

			  // Send data packet
			  //state = STATE_SEND;
		  }

		  break;



	  ////////* DEVICE WAKEUP ROUTINE *////////
	  case STATE_RUN:

		  // Start all clocks
		  if (awake == 1)
		  {
			  awake = 0;
			  SystemClock_Config();
			  HAL_ResumeTick();

			  // Reset wake up flag
			  __HAL_RTC_ALARM_CLEAR_FLAG(&hrtc, RTC_FLAG_ALRAF);
			  HAL_RTC_DeactivateAlarm(&hrtc, RTC_ALARM_A);

			  HAL_TIM_Base_Init(&htim2);
			  HAL_TIM_Base_Init(&htim3);
			  HAL_NVIC_EnableIRQ(TIM2_IRQn); 	// Disable Timer 2 interrupt
			  HAL_NVIC_EnableIRQ(TIM3_IRQn); 	// Disable Timer 3 interrupt

			  // Enable power to humidity probe and to voltage divider for battery measurement
			  HAL_GPIO_WritePin(EHUM_PWR_GPIO_Port, EHUM_PWR_Pin, GPIO_PIN_SET);
			  if (measurements.bat_period_counter >= READ_VBAT_PERIOD) HAL_GPIO_WritePin(D_VBAT_EN_GPIO_Port, D_VBAT_EN_Pin, GPIO_PIN_SET);
			  HAL_Delay(100);

			  HAL_ADC_Init(&hadc);
			  HAL_ADC_Start(&hadc);

		  }

		  if (measurements.ADC_read_cnt == 0)
		  {
			  /* BME280 */
			#ifndef SLEEP_MODE_STOP
			  status += BME280_Reset(&bme280, &hi2c2);
			  HAL_Delay(200);
			  status += BME280_ReadDeviceID(&bme280, &hi2c2);
			  status += BME280_ReadCalibData(&bme280, &hi2c2);
			  status += BME280_Init(&bme280, &hi2c2);
			#endif

			  HAL_TIM_Base_Start_IT(&htim2);
			  HAL_TIM_Base_Start_IT(&htim3);
		  }

		  if (measurements.ADC_read_end == 1 && measurements.ADC_read == 1)
		  {
			  // Read analog values
			  if (measurements.bat_period_counter >= READ_VBAT_PERIOD) measurements.bat_voltage[measurements.ADC_read_cnt] = ADC_Read_Battery(&measurements.ADC_values[0]);
			  measurements.earth_hum[measurements.ADC_read_cnt] = ADC_Read_EHum(&measurements.ADC_values[1], &delta);
			  measurements.ADC_read_cnt ++;

			  measurements.ADC_read_end = 0; 		// reset ADC read flag
			  measurements.ADC_read = 0; 			// reset timer read flag
			  HAL_TIM_Base_Start_IT(&htim2);

			  // Calculate average values
			  if (measurements.ADC_read_cnt == 5)
			  {
				  measurements.ADC_read_cnt = 0;
				  HAL_TIM_Base_Stop_IT(&htim2);

				  // Disable power to humidity probe and to voltage divider for battery measurement
				  HAL_GPIO_WritePin(EHUM_PWR_GPIO_Port, EHUM_PWR_Pin, GPIO_PIN_RESET);
				  if (measurements.bat_period_counter >= READ_VBAT_PERIOD) HAL_GPIO_WritePin(D_VBAT_EN_GPIO_Port, D_VBAT_EN_Pin, GPIO_PIN_RESET);

				  /* Calculate average battery voltage */

				  // Reset values
				  if (measurements.bat_period_counter >= READ_VBAT_PERIOD) measurements.battery_voltage = 0; // Between reads keep the same voltage
				  measurements.earth_humidity = 0;

				  // Sum the measured values
				  for (int i = 0; i < 5; i++)
				  {
					  if (measurements.bat_period_counter >= READ_VBAT_PERIOD) measurements.battery_voltage += measurements.bat_voltage[i];
					  measurements.earth_humidity += measurements.earth_hum[i];
				  }

				  // Calculate average value
				  if (measurements.bat_period_counter >= READ_VBAT_PERIOD) measurements.battery_voltage /= 5;
				  measurements.earth_humidity /= 5;

				  if (measurements.bat_period_counter >= READ_VBAT_PERIOD) measurements.bat_period_counter = 0; // Reset hour counter for battery measurement

				  // Read all data from BME280 sensor
				  BME280_GoToFromSleep(&bme280, &hi2c2, 1); // wake-up
				  HAL_Delay(100);
				  BME280_ReadAllData(&bme280, &hi2c2);
				  //BME280_GoToFromSleep(&bme280, &hi2c2, 0); // sleep

				  // LoRa module
				#ifndef SLEEP_MODE_STOP
				  RFM95W_Struct_Init(&rfm95_handle);

				  // Initialise RFM95 module.
				  if (!rfm95_init(&rfm95_handle)) status += 10; // Increase error counter for 10 to detect LoRa error (data can't be send)

				  // All that flags must be cleard to get stable boot
				  NVIC_ClearPendingIRQ(EXTI1_IRQn); 		// Clear EXTI1 NVIC pending flag
				  NVIC_ClearPendingIRQ(EXTI3_IRQn); 		// Clear EXTI3 NVIC pending
				  NVIC_ClearPendingIRQ(EXTI15_10_IRQn); 	// Clear EXTI15_10 NVIC pending flag
				  __HAL_GPIO_EXTI_CLEAR_IT(DIO0_Pin);
				  __HAL_GPIO_EXTI_CLEAR_IT(DIO5_Pin);
				  HAL_NVIC_EnableIRQ(EXTI3_IRQn);
				  HAL_NVIC_EnableIRQ(EXTI1_IRQn);
				  //HAL_NVIC_EnableIRQ(EXTI15_10_IRQn); 	// Bricks the program, inturrupt is not needed -> only for RX
				#endif

				  // Check if everthing is OK (voltage and sensors)
				  if (measurements.battery_voltage < VBAT_CRYTHICAL) status++; // TODO Vbat NEED TO BE SET

				  lora_data.errSendCnt += status;

				  if (status < 10)
				  {
					  state = STATE_SEND;
				  }
				  else
				  {
					  state = STATE_ERROR;
				  }
			  }
		  }

		  break;



	  ////////* SEND DATA *////////
	  case STATE_SEND:

		  // Collect and change data for sending
		  if (lora_data.errSendCnt > 0) lora_data.error = 1;					// Flag if device is in error
		  lora_data.battery = (uint8_t)(measurements.battery_voltage * 10);		// Battery voltage [3.5V -> 35V, no float]
		  lora_data.air_temperature = (int32_t)(bme280.Temp_C);					// Air temperature [test for negative value]
		  lora_data.air_humidity = (uint8_t)(bme280.Hum_Perc);					// Air humidity in percents [0-100%]
		  lora_data.air_pressure = (uint32_t)(bme280.Press_Pa);					// Air pressure [saved in two uint8_t]
		  lora_data.earth_humudity = (uint8_t)(measurements.earth_humidity);	// Humidity value of earth in percents [0-100%]

		  // Data packet that will be send (modify if needed)
		  uint8_t data_packet[14];

		  data_packet[0] = DEVICE_ID;                              // Device ID number
		  data_packet[1] = lora_data.error;                        // Error flag
		  data_packet[2] = lora_data.errSendCnt;                   // No. of errors
		  data_packet[3] = lora_data.battery;                      // battery voltage

		  // Encode air_temperature (int32_t -> 4 bytes)
		  data_packet[4] = (uint8_t)(lora_data.air_temperature & 0xFF);
		  data_packet[5] = (uint8_t)((lora_data.air_temperature >> 8) & 0xFF);
		  data_packet[6] = (uint8_t)((lora_data.air_temperature >> 16) & 0xFF);
		  data_packet[7] = (uint8_t)((lora_data.air_temperature >> 24) & 0xFF);

		  // Encode air_humidity
		  data_packet[8] = lora_data.air_humidity;

		  // Encode air_pressure (uint32_t -> 4 bytes)
		  data_packet[9] = (uint8_t)(lora_data.air_pressure & 0xFF);
		  data_packet[10] = (uint8_t)((lora_data.air_pressure >> 8) & 0xFF);
		  data_packet[11] = (uint8_t)((lora_data.air_pressure >> 16) & 0xFF);
		  data_packet[12] = (uint8_t)((lora_data.air_pressure >> 24) & 0xFF);

		  // Encode earth_humidity
		  data_packet[13] = lora_data.earth_humudity;

		  // Read number of TX packets from flash
		#ifdef USE_EEPROM
		  EEPROM_Read_Data(FLASH_EEPROM_BASE, &tx_count, 1); // Read from eeprom
		#else
		  Flash_Read_Data(FLASH_START_ADDR, &tx_count, 1); // Read from flash 1 = one word
		#endif

		  rfm95_handle.config.tx_frame_count = tx_count;

		  status = rfm95_send_receive_cycle(&rfm95_handle, data_packet, sizeof(data_packet));

		  if (!status) // test_data_packet
		  {
			  lora_data.errSendCnt++; // Not used
			  state = STATE_GO_SLEEP;
		  }
		  else
		  {
			  // Write number of TX packets to flash
			  uint32_t temp_data = (uint32_t)rfm95_handle.config.tx_frame_count;

			#ifdef USE_EEPROM
			  EEPROM_Write_Data(FLASH_EEPROM_BASE, &temp_data, 1);	// Write to eeprom
			#else
			  Flash_Write_Data(FLASH_START_ADDR, &temp_data, 1); 	// Write to flash 1 = one word
			#endif

			  state = STATE_GO_SLEEP;
		  }



		  // Reset error counter
		  status = 0;
		  lora_data.errSendCnt = 0;

		  break;




	  ////////* PUT DEVICE TO SLEEP *////////
	  case STATE_GO_SLEEP:

		  HAL_RTC_GetTime(&hrtc, &time, RTC_FORMAT_BIN);
		  HAL_RTC_GetDate(&hrtc, &date, RTC_FORMAT_BIN);

		  // Based on defines select sleep period
		#ifdef SLEEP_PERIOD_TEST
		  time.Seconds += 10;
		#endif

		#ifdef SLEEP_PERIOD_ONE_MINUTE
		  time.Minutes += 1;
		#endif

		#ifdef SLEEP_PERIOD_15_MINUTES
		  time.Minutes += 15;
		#endif

		#ifdef SLEEP_PERIOD_HALF_HOUR
		  time.Minutes += 30;
		#endif

		#ifdef SLEEP_PERIOD_ONE_HOUR
		  time.Hours += 1;
		#endif

		#ifdef SLEEP_PERIOD_CUSTOM
		  time.Minutes += SLEEP_PERIOD_CUSTOM;
		#endif


		  if(time.Seconds >= 60)
		  {
			  time.Minutes ++;
			  time.Seconds = 0;
		  }

		  if(time.Minutes >= 60)
		  {
			  time.Hours++;
			  time.Minutes = 0;
		  }

		  if(time.Hours > 23)
		  {
			  time.Hours = 0;
		  }

		  sAlarm.Alarm 					= RTC_ALARM_A;
		  sAlarm.AlarmTime.Hours 		= time.Hours;
		  sAlarm.AlarmTime.Minutes 		= time.Minutes;
		  sAlarm.AlarmTime.Seconds 		= time.Seconds;
		  sAlarm.AlarmMask            	= RTC_ALARMMASK_DATEWEEKDAY; 	// ignore date
		  sAlarm.AlarmDateWeekDaySel  	= RTC_ALARMDATEWEEKDAYSEL_DATE;
		  sAlarm.AlarmDateWeekDay     	= 1;                           	// don’t care
		  sAlarm.Alarm                	= RTC_ALARM_A;

		  HAL_RTC_DeactivateAlarm(&hrtc, RTC_ALARM_A);

		  __HAL_PWR_CLEAR_FLAG(PWR_FLAG_WU);
		  __HAL_RTC_ALARM_CLEAR_FLAG(&hrtc, RTC_FLAG_ALRAF);
		  if (HAL_RTC_SetAlarm_IT(&hrtc, &sAlarm, RTC_FORMAT_BIN) != HAL_OK) Error_Handler();

		  HAL_NVIC_SetPriority(RTC_Alarm_IRQn, 0, 0);
		  HAL_NVIC_EnableIRQ(RTC_Alarm_IRQn);


		  // Put devices and sensors to sleep
		  rfm95_goto_sleep(&rfm95_handle); // If the module is not in sleep mode (it should be)
		  BME280_GoToFromSleep(&bme280, &hi2c2, 0); // If the sensor is not in sleep mode (it should be)

		  // Disable power to humidity probe and to voltage divider for battery measurement
		  HAL_GPIO_WritePin(EHUM_PWR_GPIO_Port, EHUM_PWR_Pin, GPIO_PIN_RESET);
		  HAL_GPIO_WritePin(D_VBAT_EN_GPIO_Port, D_VBAT_EN_Pin, GPIO_PIN_SET);

		  // Set SPI CS pins
		  HAL_GPIO_WritePin(SPI1_CS_EX_GPIO_Port, SPI1_CS_EX_Pin, GPIO_PIN_SET);
		  HAL_GPIO_WritePin(SPI2_NSS_GPIO_Port, SPI2_NSS_Pin, GPIO_PIN_SET);

		  // Stop Timers if they running and disable their interrupts
		  HAL_TIM_Base_Stop_IT(&htim2); // Stop Timer 2
		  HAL_TIM_Base_Stop_IT(&htim3); // Stop Timer 3
		  HAL_NVIC_DisableIRQ(TIM2_IRQn); // Disable Timer 2 interrupt
		  HAL_NVIC_DisableIRQ(TIM3_IRQn); // Disable Timer 3 interrupt

		  HAL_ADC_Stop(&hadc);
		  HAL_ADC_DeInit(&hadc);

		  // Disable IRQs from LoRa module
		  HAL_NVIC_DisableIRQ(EXTI1_IRQn);
		  HAL_NVIC_DisableIRQ(EXTI3_IRQn);
		  NVIC_ClearPendingIRQ(EXTI1_IRQn);
		  NVIC_ClearPendingIRQ(EXTI3_IRQn);
		  __HAL_GPIO_EXTI_CLEAR_IT(DIO0_Pin);
		  __HAL_GPIO_EXTI_CLEAR_IT(DIO5_Pin);

		  // Reconfigure to analog (or input with pull-down) for sleep
		  GPIO_InitTypeDef g = {0};
		  g.Mode = GPIO_MODE_ANALOG;
		  g.Pull = GPIO_NOPULL;
		  g.Speed = GPIO_SPEED_FREQ_LOW;
		  g.Pin = DIO0_Pin | DIO5_Pin;
		  HAL_GPIO_Init(GPIOB, &g);


		  //HAL_SPI_DeInit(&hspi1);
		  //HAL_SPI_DeInit(&hspi2);
		  //HAL_I2C_DeInit(&hi2c1);
		  //HAL_I2C_DeInit(&hi2c2);
		  //HAL_UART_DeInit(&huart1);


		  HAL_PWREx_EnableUltraLowPower();
		  HAL_PWREx_DisableFastWakeUp();
		  HAL_PWR_DisablePVD();
		  HAL_PWR_DisableWakeUpPin(PWR_WAKEUP_PIN1);

		  // Set sleep mode
		#ifdef SLEEP_MODE_STOP
		  SET_BIT(FLASH->ACR, FLASH_ACR_SLEEP_PD);

		  HAL_PWREx_EnableUltraLowPower();
		  HAL_PWREx_DisableFastWakeUp();
		  HAL_PWR_DisablePVD();

		  HAL_DBGMCU_DisableDBGStopMode();
		  HAL_PWR_EnterSTOPMode(PWR_LOWPOWERREGULATOR_ON, PWR_STOPENTRY_WFI); // PWR_MAINREGULATOR_ON

		#endif

		#ifndef SLEEP_MODE_STOP
		  HAL_DBGMCU_DisableDBGStandbyMode();
		  HAL_PWR_EnterSTANDBYMode();
		#endif

		  // Resume clock and ticks
		  SystemClock_Config();
		  HAL_ResumeTick();

		  // Reset wake up flag
		  HAL_RTC_DeactivateAlarm(&hrtc, RTC_ALARM_A);
		  __HAL_RTC_ALARM_CLEAR_FLAG(&hrtc, RTC_FLAG_ALRAF);


		  break;

	  case STATE_ERROR:

		  ////////* INIT ROUTINE FAILED *////////

		  break;

	  default:

		  ////////* UNDEFINED STATE *////////

		  break;

	  }
    /* USER CODE END WHILE */

    /* USER CODE BEGIN 3 */
  }
  /* USER CODE END 3 */
}

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
/* USER CODE BEGIN 4 */
// Wake up interrupt - STOP mode //
void HAL_RTC_AlarmAEventCallback(RTC_HandleTypeDef *hrtc)
{
	awake = 1;
	if (state != STATE_INIT) state = STATE_RUN;
}


// Wake up interrupt - STANDBY mode //
void wake_up_from_standby_handler(void)
{
    awake = 1;
	state = STATE_RUN;
}


// TIMER Interrupt //
void HAL_TIM_PeriodElapsedCallback (TIM_HandleTypeDef * htim)
{
	/* TIMER 2 - 10Hz (Read sensors to average their values) */
	if (htim->Instance == TIM2)
	{
		if (measurements.ADC_read == 0)
		{
			HAL_TIM_Base_Stop_IT(&htim2);
			adc_substate = 0;                  // start with battery in this cycle
			ADC_SelectChannel(ADC_CHANNEL_1);  // PA1 (AN_BAT)
			HAL_ADC_Start_IT(&hadc);
			measurements.ADC_read = 1;
		}
	}

	if (htim->Instance == TIM3)
	{
		tim3_tick_msb += 0x10000; // Increment the MSB by 0x10000 each time TIM2 overflows
		HAL_TIM_Base_Start_IT(&htim3);
	}
}


// ADC interrupt
void HAL_ADC_ConvCpltCallback(ADC_HandleTypeDef* hadc)
{
    if (hadc->Instance == ADC1)
    {
    	if (adc_substate == 0)
		{
			// 1. conversion: BATTERY
			measurements.ADC_values[0] = HAL_ADC_GetValue(hadc);

			// 2. conversion: SOIL HUMIDITY
			adc_substate = 1;
			ADC_SelectChannel(ADC_CHANNEL_2);
			HAL_ADC_Start_IT(hadc);
			return;
		}
		else
		{
			// 2nd conversion: HUMIDITY
			measurements.ADC_values[1] = HAL_ADC_GetValue(hadc);

			HAL_ADC_Stop_IT(hadc);
			measurements.ADC_read_end = 1;
			adc_substate = 0;
		}
    }
}


// Switch between channels of ADC
static void ADC_SelectChannel(uint32_t channel)
{
    ADC_ChannelConfTypeDef sConfig = {0};
    sConfig.Channel      = channel;                 // ADC_CHANNEL_1 or _2
    sConfig.Rank         = ADC_REGULAR_RANK_1;
    sConfig.SamplingTime = ADC_SAMPLETIME_4CYCLES;
    HAL_ADC_ConfigChannel(&hadc, &sConfig);
}


// Read battery voltage //
float ADC_Read_Battery(uint32_t* ADC_value)
{
	// If LDO is used to power the board
#ifdef LDO_USE
	float Vout = ((float)(*ADC_value * LDO_OUT_U)) / 4095;
	float voltage = ((BAT_R1 + BAT_R2) * (Vout / BAT_R2));
	return (float) voltage;
#endif

	// If board is directly powered from battery
#ifndef LDO_USE
	float Vout = ((float)(*ADC_value * BAT_U)) / 4095;
	float voltage = ((BAT_R1 + BAT_R2) * (Vout / BAT_R2));
	return (float) voltage;
#endif
}
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

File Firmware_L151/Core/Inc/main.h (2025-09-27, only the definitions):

#define BOOST_EN_Pin GPIO_PIN_0
#define BOOST_EN_GPIO_Port GPIOA
#define AN_BAT_Pin GPIO_PIN_1
#define AN_BAT_GPIO_Port GPIOA
#define AN_E_HUM_Pin GPIO_PIN_2
#define AN_E_HUM_GPIO_Port GPIOA
#define EHUM_PWR_Pin GPIO_PIN_3
#define EHUM_PWR_GPIO_Port GPIOA
#define SPI1_CS_EX_Pin GPIO_PIN_4
#define SPI1_CS_EX_GPIO_Port GPIOA
#define D_VBAT_EN_Pin GPIO_PIN_0
#define D_VBAT_EN_GPIO_Port GPIOB
#define DIO5_Pin GPIO_PIN_1
#define DIO5_GPIO_Port GPIOB
#define DIO5_EXTI_IRQn EXTI1_IRQn
#define UNUSED1_Pin GPIO_PIN_2
#define UNUSED1_GPIO_Port GPIOB
#define SPI2_NSS_Pin GPIO_PIN_12
#define SPI2_NSS_GPIO_Port GPIOB
#define RESET_Pin GPIO_PIN_8
#define RESET_GPIO_Port GPIOA
#define DIO2_Pin GPIO_PIN_11
#define DIO2_GPIO_Port GPIOA
#define DIO1_Pin GPIO_PIN_15
#define DIO1_GPIO_Port GPIOA
#define DIO0_Pin GPIO_PIN_3
#define DIO0_GPIO_Port GPIOB
#define DIO0_EXTI_IRQn EXTI3_IRQn
#define DIO4_Pin GPIO_PIN_4
#define DIO4_GPIO_Port GPIOB
#define DIO3_Pin GPIO_PIN_5
#define DIO3_GPIO_Port GPIOB
#define LDO_USE								// Comment this line if you don't use LDO on PCB - power from battery
#define BAT_U				4.2				// Set voltage of the battery
#define LDO_OUT_U			3.6				// Measured voltage of the LDO used to calculate earth humidity
#define BAT_R1 				100				// Resistor 1 in voltage divider for battery voltage
#define BAT_R2 				100				// Resistor 2 in voltage divider for battery voltage
#define EARTH_HUM_DRY_VAL	2156			// Return value of ADC for dry sensor (set for each sensor)
#define EARTH_HUM_WET_VAL	1060			// Return value of ADC for wet sensor (set for each sensor)
#define USE_EEPROM							// Use EEPROM instead of flash to save data
#define SLEEP_PERIOD_HALF_HOUR				// Amount of time for MCU to sleep - 30min
#define RTC_CLOCK_REF		32768			// Frequency of the RTC clock
#define READ_VBAT_PERIOD	24				// Read the battery only every N HOURS to decrease the power consumption
#define VBAT_CRYTHICAL		2.4				// Minimum battery voltage allowed - must be set
#define STATE_INIT			0				// State of initialization - device power on
#define STATE_FIRST_CONN	1				// State where node gets first connection		///////// STANDBY MODE NOT TESTED!!! /////////
#define STATE_RUN			2				// State for main code
#define STATE_SEND			3				// State for sending data over LoRa or SIM
#define STATE_GO_SLEEP		4				// State where mcu is put to sleep
#define STATE_ERROR			5				// Init routine failed

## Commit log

2024-11-24 Update: PCB, firmware, server app
2024-12-16 Update
    PCB: added pull-downs on IRQ pins, SW: stable EXTI, reliable measurements
    [LoRa_Node.kicad_pcb, LoRa_Node.kicad_sch]
2024-12-25 Update
    Humidity probe is rewired from the 3v3 to MCU pin for power
    [LoRa_Node.kicad_pcb, LoRa_Node.kicad_sch]
2024-12-28 README Update
    [LoRa_Node.kicad_pcb]
2025-01-25 Update:
    4V bus update (step-up converter)
    [LoRa_Node.kicad_pcb, LoRa_Node.kicad_sch]
2025-04-06 added Docker image for all the server applications
    [LoRa_Node.kicad_pcb, LoRa_Node.kicad_sch]
2025-05-31 PCB modifications, MCU replacement and FW migration
    [LoRa_Node-B_Cu.gbr, LoRa_Node-B_Mask.gbr, LoRa_Node-B_Paste.gbr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]
2025-06-19 ported SW to now MCU - untested
    [LoRa_Node.kicad_sch]
2025-08-02 update
    working code for new mcu, current consumption still 900uA
    [LoRa_Node-B_Cu.gbr, LoRa_Node-B_Mask.gbr, LoRa_Node-B_Paste.gbr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]
2025-08-02 update
    updated PCB
    [LoRa_Node.kicad_pcb]
2025-09-07 Update
    firmware current optimisation
    [LoRa_Node.kicad_pcb, LoRa_Node.kicad_sch]
2025-09-07 Update
    PCB pdf
2025-09-24 Bugfix
    solved problem with LoRa packet counter (flash write error after sleep)
    [LoRa_Node.kicad_sch]
2025-09-27 Bugfix
    earth humidity and MBE280 power on delay
    [LoRa_Node_GHv2.ioc, main.c, main.h]

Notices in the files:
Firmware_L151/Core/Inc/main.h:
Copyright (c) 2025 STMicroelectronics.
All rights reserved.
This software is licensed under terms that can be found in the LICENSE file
